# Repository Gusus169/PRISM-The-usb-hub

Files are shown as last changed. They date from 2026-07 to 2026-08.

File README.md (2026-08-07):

# 'PRISM' The USB Hub V2.0

### A compact 4-port USB 2.0 hub PCB featuring ESD protection,  PTC resettable fuses, and per-port LED indicators; All packed in a small keychain design form.

[Key Features](#key-features) • [PCB](#pcb) • [BOM](#bom) • [License](#license)

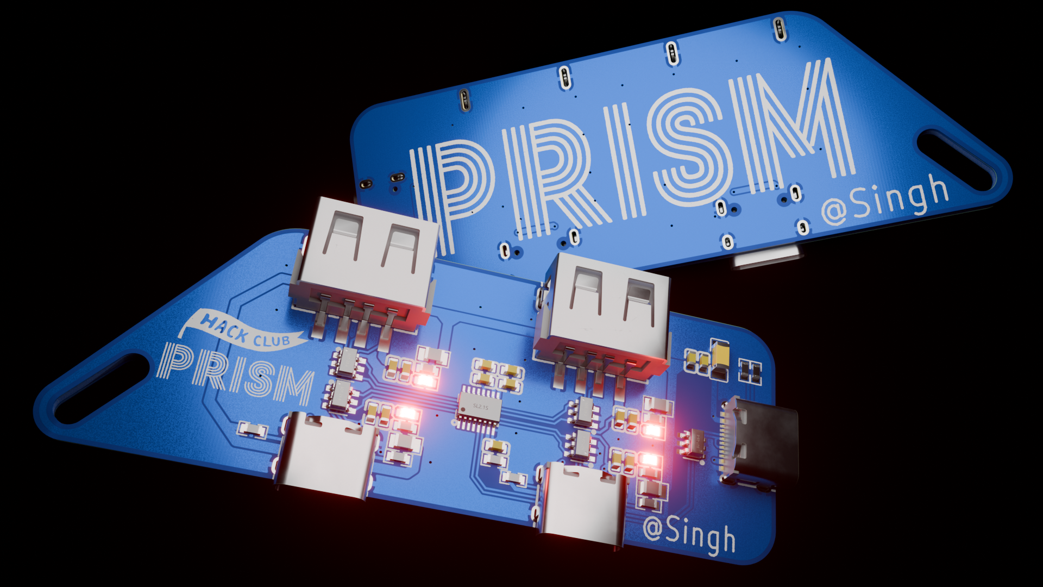
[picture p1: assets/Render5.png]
Banner1


## About

PRISM is a USB Type-C-based input USB hub that splits it into four downstream ports — just like a prism splits light. Built from scratch starting in EasyEDA Pro(V1), later moving to KiCad and finishing off with Blender animated renders, this project pushed me deep into reading datasheets, understanding circuit protection, and the difference between making something work and engineering something worth making.

## Key Features

- Main IC - SL2.1S (IC)
- Static Circuit Protection - ESD diodes on all ports
- Short-Circuit protection - PTC on all downstream ports
- Downstream port features - 2x USB-Type-C
                           - 2x USB-Type-A
- Upstream port - USB-Type-C
- Multi-Layer capacitor decoupling
- Compact 2-layer PCB, designed to be a keychain at ~3" × 1.2".

## PCB

Designed in EasyEDA Pro(V1), Further Refined in KiCad(V2).

### Schematic

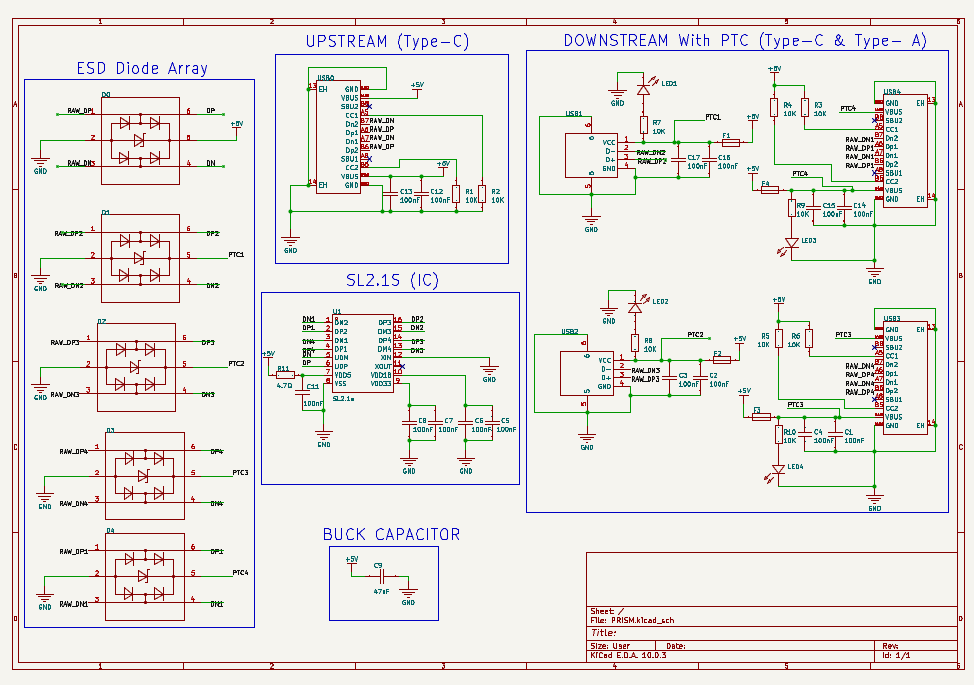
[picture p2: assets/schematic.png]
Schematic


### PCB

**Front:**

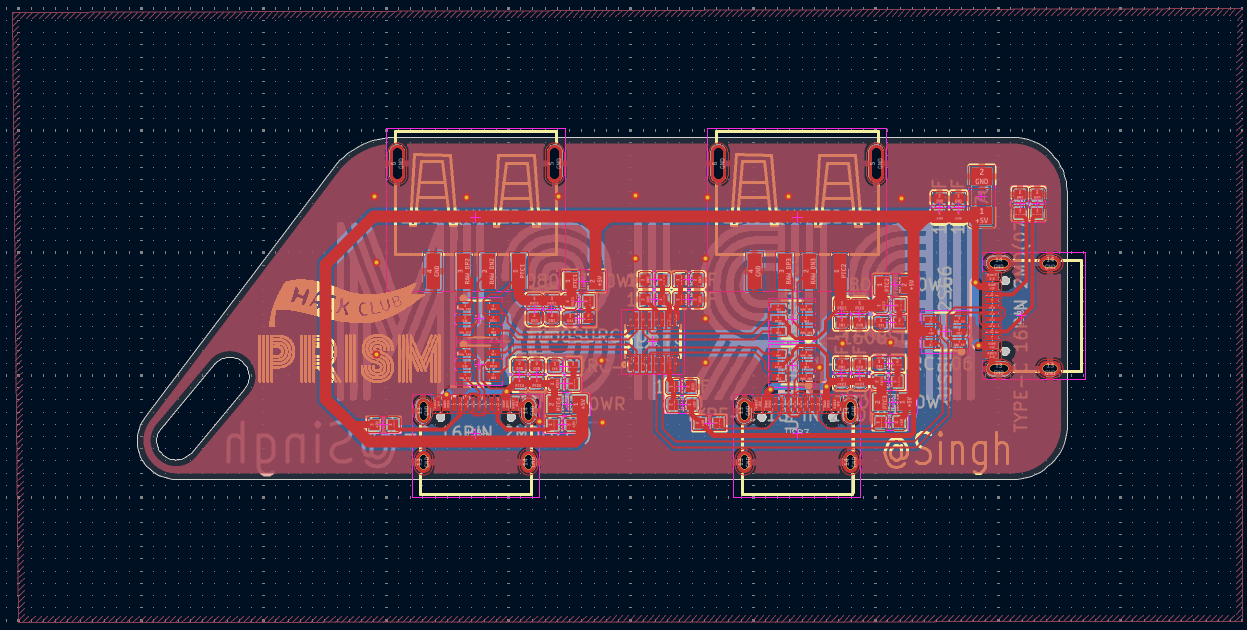
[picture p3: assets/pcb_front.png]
PCB Front


**Back:**

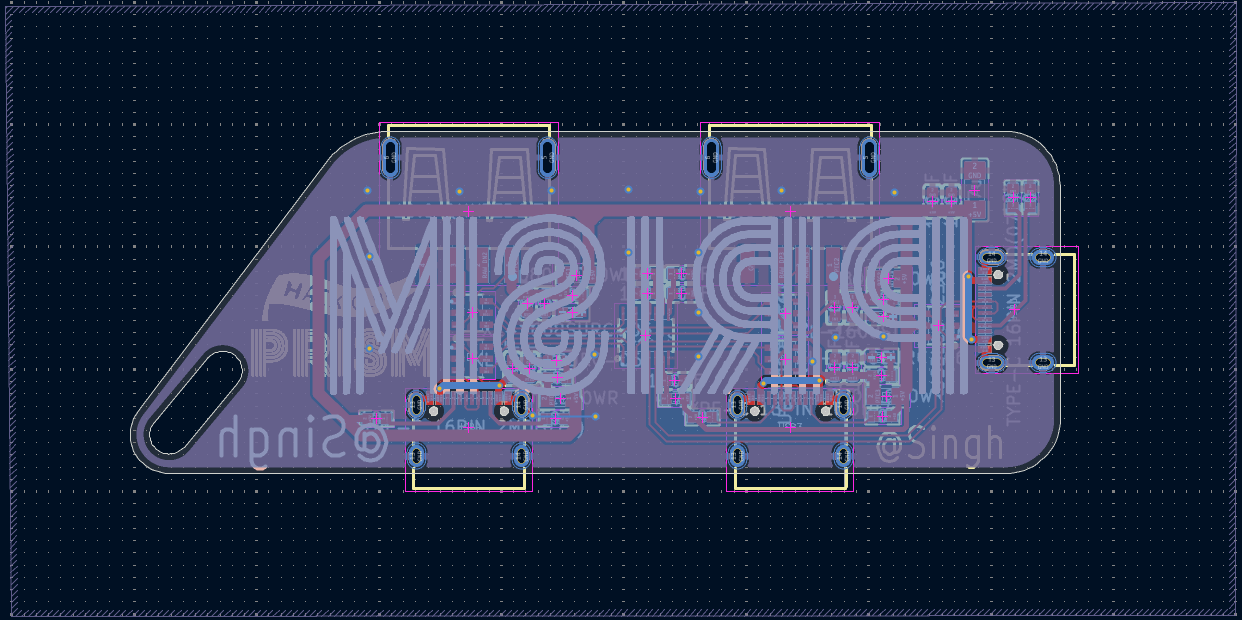
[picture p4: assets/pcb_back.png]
PCB Back


### KiCad Renders 

**Front:**

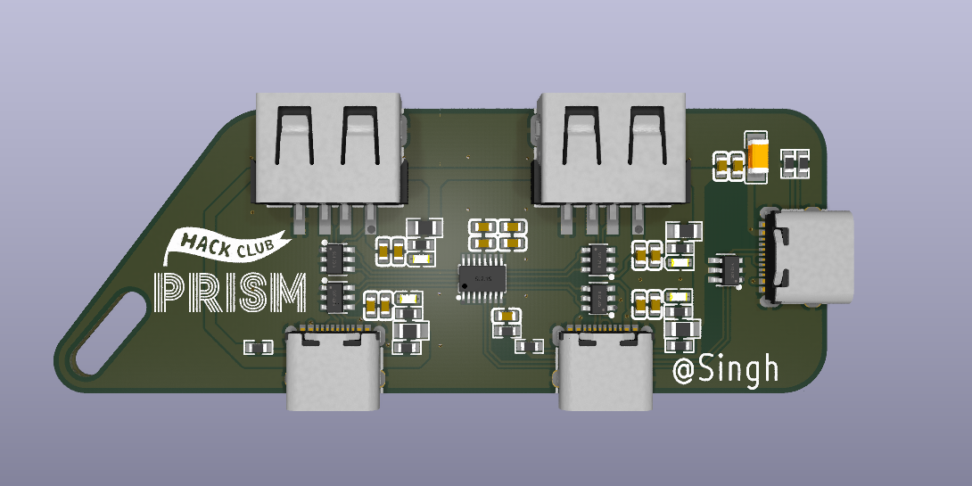
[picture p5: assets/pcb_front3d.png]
PCB Front


**Back:**

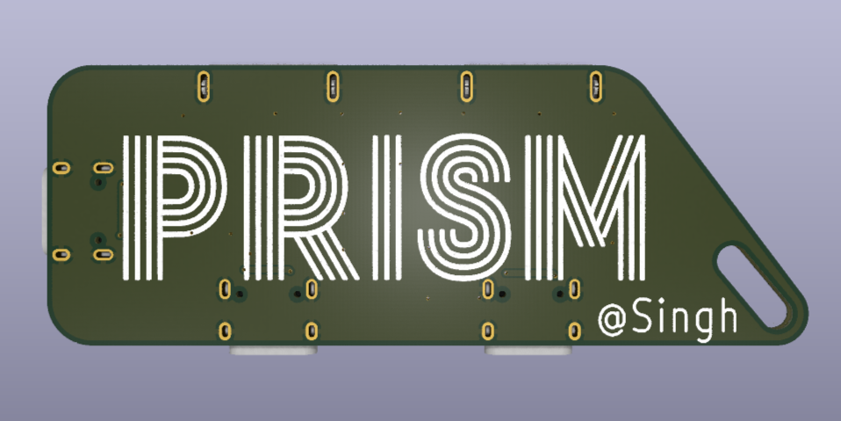
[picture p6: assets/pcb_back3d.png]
PCB Back


## BOM

|Index|	LCSC#	| Product Name|	Manufacturer|Package|	Design Refrence#|	Quantity|	Product Link|
|-----|---|---|---|---|---|---|---|
|1	|C207022|	0805L050WR|	Littelfuse|	805|	F1,F2,F3,F4|	4|	https://www.lcsc.com/product-detail/C207022.html|
|2	|C668591|	10.0 QHHTZB6.3|	SHOU HAN|	SMD|	USB1,USB2	|2	|https://www.lcsc.com/product-detail/C668591.html|
|3	|C1591|	CL10B104KB8NNNC|	Samsung Electro-Mechanics|	603	|C1-8,C11-17|	15|https://www.lcsc.com/product-detail/C1591.html|
|4	|C2906982|	FRC0603F1002TS|	FOJAN|	603|	R1,R10,R2,R3,R4,R5,R6,R7,R8,R9|	10	|https://www.lcsc.com/product-detail/C2906982.html|
|5	|C2907035|	FRC0603F4R70TS|	FOJAN|	603|	R11|	1	|https://www.lcsc.com/product-detail/C2907035.html|
|6	|C2684433|	SL2.1s	|CoreChips|	SSOP-16|	U1|	1	|https://www.lcsc.com/product-detail/C2684433.html|
|7	|C2765186|TYPE-C 16PIN 2MD(073)|	SHOU HAN|	SMD	|USB0,USB3,USB4	|1	|https://www.lcsc.com/product-detail/C2765186.html|
|8	|C7519|	USBLC6-2SC6|	ST|	SOT-23-6L|	D0,D1,D2,D3,D4 |3	|https://www.lcsc.com/product-detail/C7519.html|
|9	|C965799|	XL-1608SURC-06|	XINGLIGHT	|603	|LED1,LED2,LED3,LED4|	5	|https://www.lcsc.com/product-detail/C965799.html|
|10|	C22367835|	HGC1206R5476M250NSPJ|	Chinocera|	1206|	C9|	4	|https://www.lcsc.com/product-detail/C22367835.html|

## What I Learned

- How to read the reference schematic provided by the manufacturer
- In-depth functionality of capacitors - Why they are used in pairs
- Functionality of ESD & PTC
- Difference in USB types and their speeds
- Differential pair routing and its importance

## Credits

This project uses:

- [EasyEDA Pro](https://pro.easyeda.com/) 
- [KiCad](https://www.kicad.org/download/)
- [JLCPCB](https://jlcpcb.com/) for PCB fabrication
- [LCSC](https://www.lcsc.com/) for component sourcing
- Based on the [Hack Club USB Hub guide](https://macondo.hackclub.com/docs/usb-hub)

## License

MIT

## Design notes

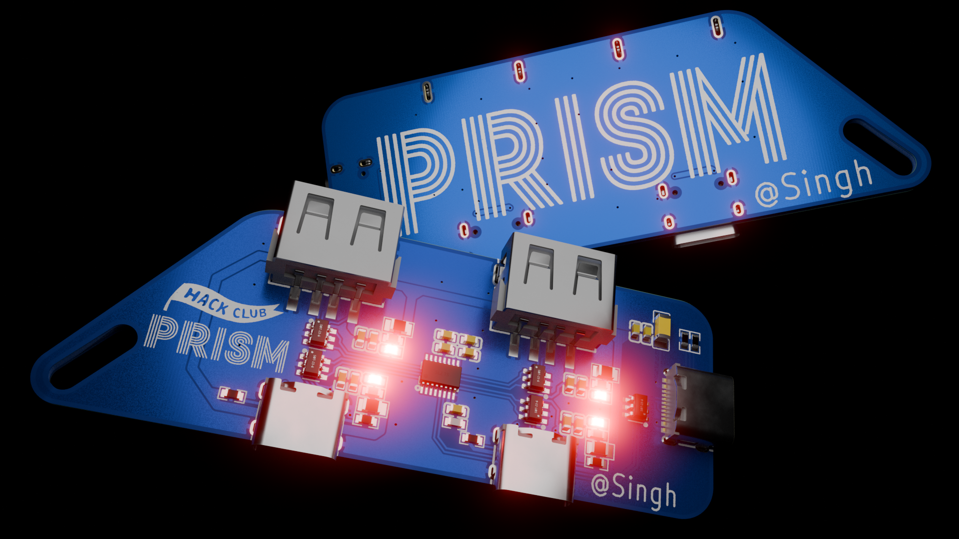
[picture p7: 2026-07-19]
assets/Render7.png

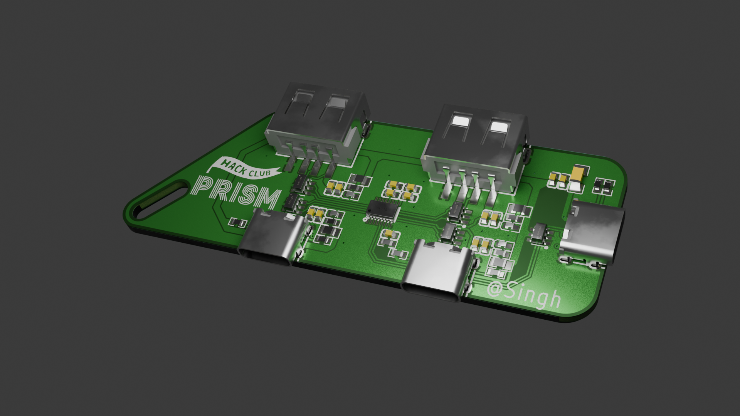
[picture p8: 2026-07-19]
assets/Render1.png

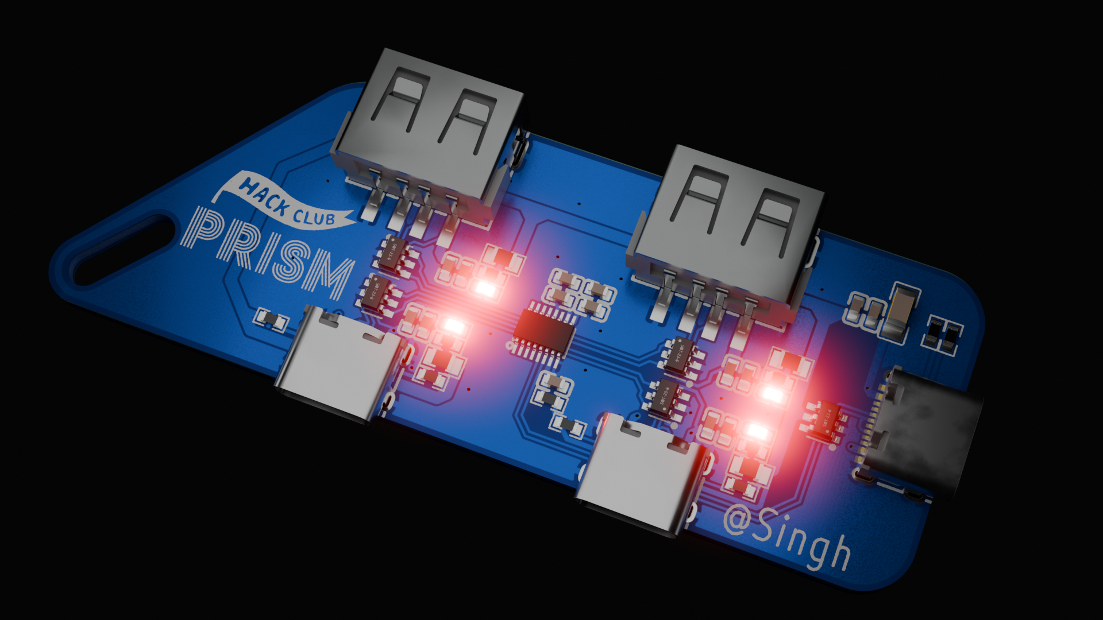
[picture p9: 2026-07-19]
assets/Render6.png

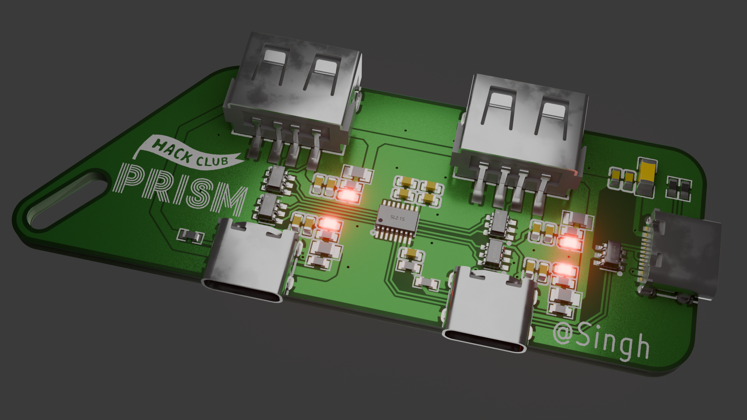
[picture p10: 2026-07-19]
assets/Render3.png

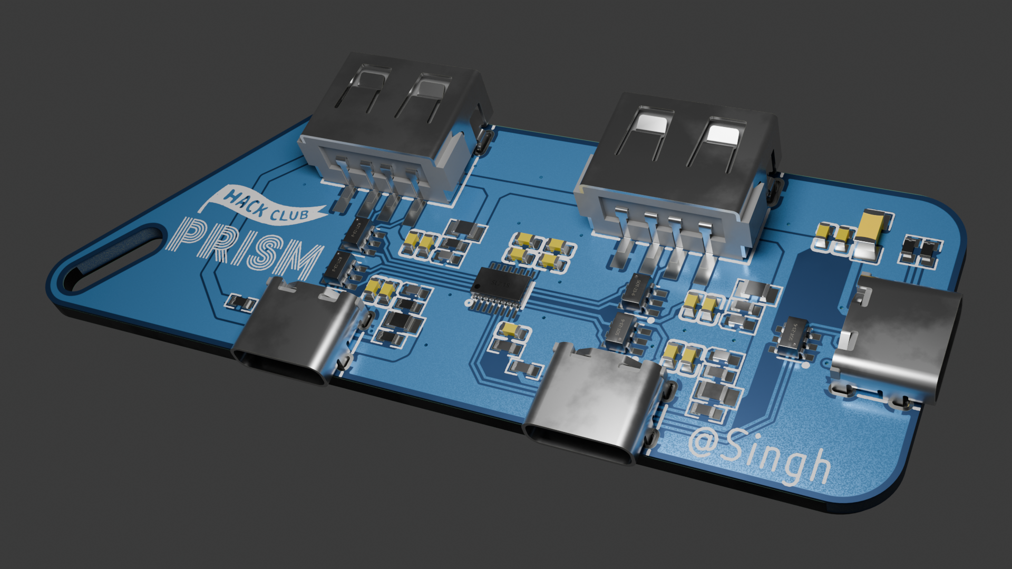
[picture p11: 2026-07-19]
assets/Render2.png

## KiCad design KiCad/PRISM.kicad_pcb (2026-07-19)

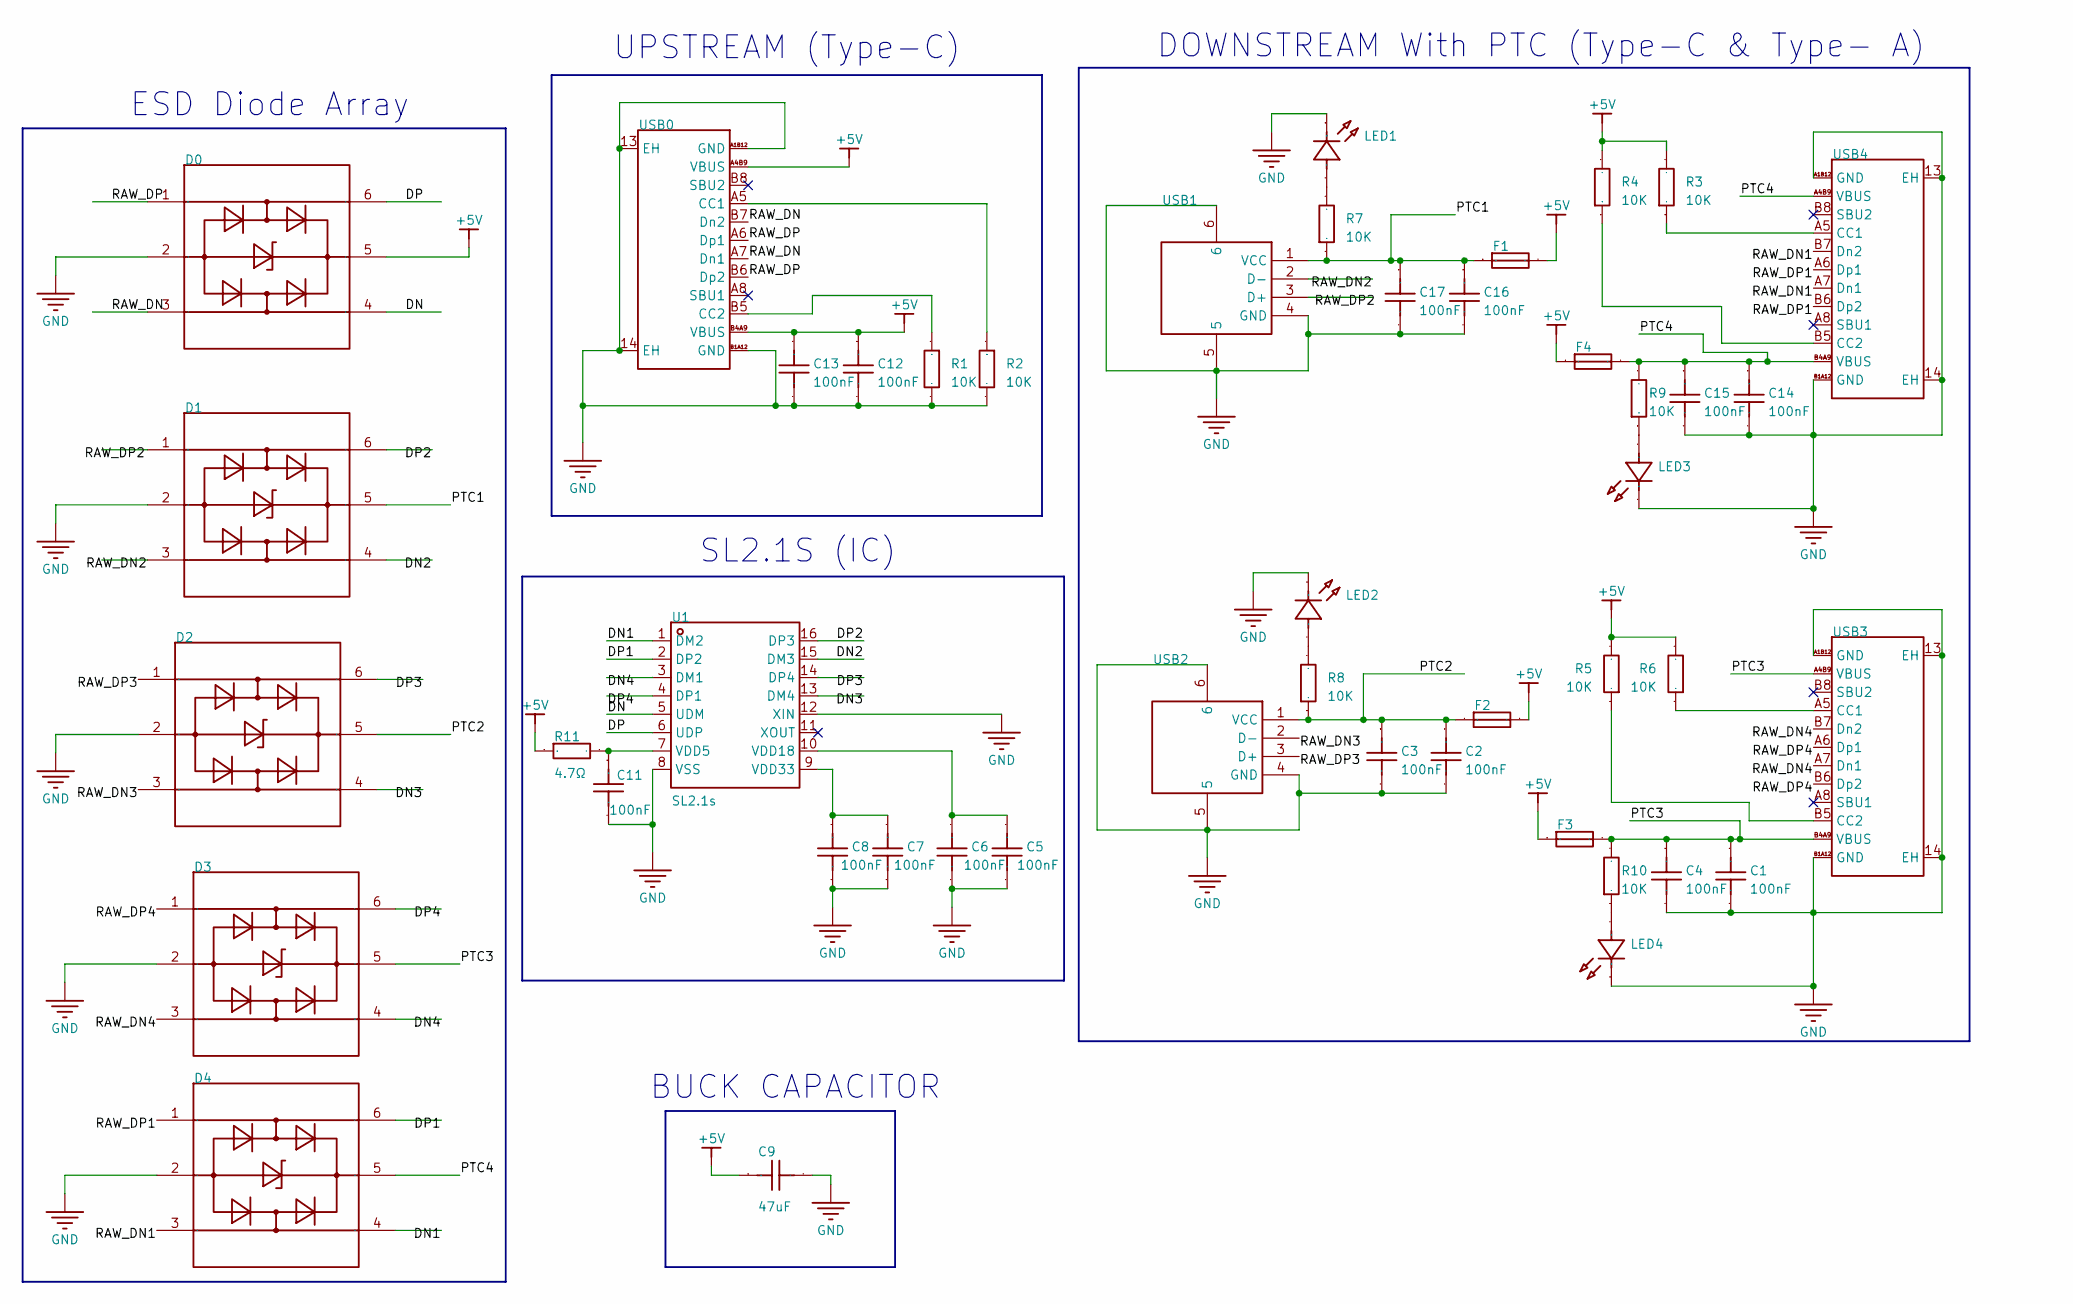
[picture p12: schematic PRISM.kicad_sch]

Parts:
C1, C2, C3, C4, C5, C6, C7, C8, C11, C12, C13, C14, C15, C16, C17: 100nF; C0603
C9: 47uF; C1206; Manufacturer Part TCC1206X5R476M100HT; LCSC Part Name 47uF ±20% 10V
D0, D1, D2, D3, D4: USBLC6-2SC6; SOT-23-6_L2.9-W1.6-P0.95-LS2.8-BL; Manufacturer Part USBLC6-2SC6; LCSC Part Name 单向ESD
F1, F2, F3, F4: 0805L050WR; R0805; Manufacturer Part 0805L050WR; LCSC Part Name 6V 500mA 0805自恢复
LED1, LED2, LED3, LED4: XL-1608SURC-06; LED0603-RD_RED; Manufacturer Part XL-1608SURC-06; LCSC Part Name 0603红色贴片式发光二极管
R1, R2, R3, R4, R5, R6, R7, R8, R9, R10: 10K; R0603
R11: 4.7Ω; R0603; Manufacturer Part 0603WAJ047JT5E; LCSC Part Name 4.7Ω ±5% 100mW 厚膜电阻
U1: SL2.1s; SSOP-16_L4.6-W2.6-P0.53-LS4.0-BL; Manufacturer Part SL2.1s; LCSC Part Name USB2.0 HUB控制器集成电路
USB0, USB3, USB4: TYPE-C 16PIN 2MD(073); USB-C-SMD_TYPE-C-16PIN-2MD-073; Manufacturer Part TYPE-C 16PIN 2MD(073); LCSC Part Name Type-C 母 卧贴
USB1, USB2: 10.0 QHHTZB6.3; USB-A-TH_10.0QHHTZB6.3; Manufacturer Part 10.0 QHHTZB6.3; LCSC Part Name 壳长10.0mm

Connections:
+5V: C9.1, C12.1, C13.1, D0.5, F1.2, F2.2, F3.1, F4.1, R3.2, R4.2, R5.2, R6.2, R11.1, USB0.A4B9 (VBUS), USB0.B4A9 (VBUS)
/DN: D0.4, U1.5 (UDM)
/DN1: D4.4, U1.1 (DM2)
/DN2: D1.4, U1.15 (DM3)
/DN3: D2.4, U1.13 (DM4)
/DN4: D3.4, U1.3 (DM1)
/DP: D0.6, U1.6 (UDP)
/DP1: D4.6, U1.2 (DP2)
/DP2: D1.6, U1.16 (DP3)
/DP3: D2.6, U1.14 (DP4)
/DP4: D3.6, U1.4 (DP1)
/PTC1: C16.1, C17.1, D1.5, F1.1, R7.1, USB1.1 (VCC)
/PTC2: C2.1, C3.1, D2.5, F2.1, R8.1, USB2.1 (VCC)
/PTC3: C1.1, C4.1, D3.5, F3.2, R10.2, USB3.A4B9 (VBUS), USB3.B4A9 (VBUS)
/PTC4: C14.1, C15.1, D4.5, F4.2, R9.2, USB4.A4B9 (VBUS), USB4.B4A9 (VBUS)
/RAW_DN: D0.3, USB0.A7 (Dn1), USB0.B7 (Dn2)
/RAW_DN1: D4.3, USB4.A7 (Dn1), USB4.B7 (Dn2)
/RAW_DN2: D1.3, USB1.2 (D-)
/RAW_DN3: D2.3, USB2.2 (D-)
/RAW_DN4: D3.3, USB3.A7 (Dn1), USB3.B7 (Dn2)
/RAW_DP: D0.1, USB0.A6 (Dp1), USB0.B6 (Dp2)
/RAW_DP1: D4.1, USB4.A6 (Dp1), USB4.B6 (Dp2)
/RAW_DP2: D1.1, USB1.3 (D+)
/RAW_DP3: D2.1, USB2.3 (D+)
/RAW_DP4: D3.1, USB3.A6 (Dp1), USB3.B6 (Dp2)
GND: C1.2, C2.2, C3.2, C4.2, C5.2, C6.2, C7.2, C8.2, C9.2, C11.2, C12.2, C13.2, C14.2, C15.2, C16.2, C17.2, D0.2, D1.2, D2.2, D3.2, D4.2, LED1.1 (K), LED2.1 (K), LED3.1 (K), LED4.1 (K), R1.2, R2.2, U1.8 (VSS), U1.12 (XIN), USB0.13 (EH), USB0.14 (EH), USB0.A1B12 (GND), USB0.B1A12 (GND), USB1.4 (GND), USB1.5, USB1.6, USB2.4 (GND), USB2.5, USB2.6, USB3.13 (EH), USB3.14 (EH), USB3.A1B12 (GND), USB3.B1A12 (GND), USB4.13 (EH), USB4.14 (EH), USB4.A1B12 (GND), USB4.B1A12 (GND)
unnamed: LED1.2 (A), R7.2
unnamed: LED2.2 (A), R8.2
unnamed: LED3.2 (A), R9.1
unnamed: LED4.2 (A), R10.1
unnamed: C11.1, R11.2, U1.7 (VDD5)
unnamed: C5.1, C6.1, U1.10 (VDD18)
unnamed: C7.1, C8.1, U1.9 (VDD33)
unnamed: R2.1, USB0.A5 (CC1)
unnamed: R1.1, USB0.B5 (CC2)
unnamed: R6.1, USB3.A5 (CC1)
unnamed: R5.1, USB3.B5 (CC2)
unnamed: R3.1, USB4.A5 (CC1)
unnamed: R4.1, USB4.B5 (CC2)

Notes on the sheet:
ESD Diode Array
DOWNSTREAM With PTC (Type-C & Type- A)
BUCK CAPACITOR
UPSTREAM (Type-C)
SL2.1S (IC)

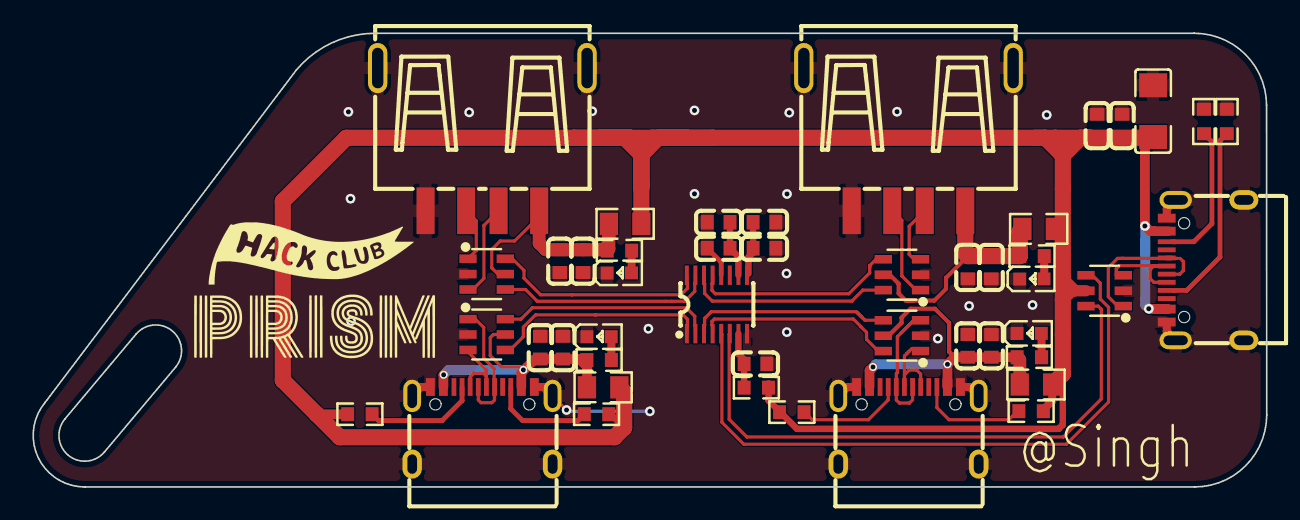
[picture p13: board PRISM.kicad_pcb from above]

Board: 2 copper layers, 76.0 x 28.0 mm, 46 parts (0 on the bottom side), 39 nets.

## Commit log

2026-06-29 README
    Updated project title and expanded description with key features, PCB design details, BOM, and lessons learned.
2026-07-19 V2 Upload
    [BOM-PRISM.csv, PRISM.kicad_pcb, PRISM.kicad_sch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]
2026-07-21 Fixed the product no on BOM
    [BOM-PRISM.csv]
2026-07-21 BOM Fix
2026-08-07 BOM with links
    Added a table for BOM details including product information and links.
